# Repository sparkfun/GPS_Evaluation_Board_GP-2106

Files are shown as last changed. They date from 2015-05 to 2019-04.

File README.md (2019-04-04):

**NOTE:** *This product has been retired from our catalog. If you are looking for more up-to-date info, please check out some of these resources to see how other users are still hacking and improving on this product.*
* *[SparkFun Forum](https://forum.sparkfun.com/)*
* *[Comments Here on GitHub](https://github.com/sparkfun/GPS_Evaluation_Board_GP-2106/issues)*
* *[IRC Channel](https://www.sparkfun.com/news/263)*

SparkFun GPS Evaluation Board - GP-2106
========================================

SparkFun GPS Evaluation Board - GP-2106

[*SparkFun GPS Evaluation Board - GP-2106 (GPS-10995)*](https://www.sparkfun.com/products/10995)

The GP-2106 Evaluation Board features everything you need to get the [GP-2106 module](https://www.sparkfun.com/products/retired/10890) talking to your system. 
Because the GP-2106 is a 1.8V module, we’ve provided level-shifting for 3.3 and 5V systems. 
The board also features a PPS status LED, on/off button and an FTDI Basic compatible header!

Repository Contents
-------------------

* **/Hardware** - Eagle design files (.brd, .sch)
* **/Production** - Production panel files (.brd)

Documentation
--------------
* **[SparkFun Fritzing repo](https://github.com/sparkfun/Fritzing_Parts)** - Fritzing diagrams for SparkFun products.
* **[SparkFun 3D Model repo](https://github.com/sparkfun/3D_Models)** - 3D models of SparkFun products. 

License Information
-------------------
This product is _**open source**_! 

The **hardware** is released under [Creative Commons ShareAlike 4.0 International](https://creativecommons.org/licenses/by-sa/4.0/).

Please use, reuse, and modify these files as you see fit. Please maintain attribution to SparkFun Electronics and release anything derivative under the same license.

Distributed as-is; no warranty is given.

- Your friends at SparkFun.

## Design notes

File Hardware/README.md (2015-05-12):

SparkFun <PRODUCT NAME> Design Files
=====================================

The .sch and .brd files hare are Eagle CAD schematic and PCB design files from SparkFun Electronics.
A freeware version of Eagle can be found [here](http://www.cadsoftusa.com/download-eagle/freeware/). 

License
---------
This product is open source! 
The hardware is released under [Creative Commons ShareAlike 4.0 International](https://creativecommons.org/licenses/by-sa/4.0/).

Please use, reuse, and modify these files as you see fit. Please maintain attribution to SparkFun Electronics and release anything derivative under the same license.

Distributed as-is; no warranty is given.

- Your friends at SparkFun.

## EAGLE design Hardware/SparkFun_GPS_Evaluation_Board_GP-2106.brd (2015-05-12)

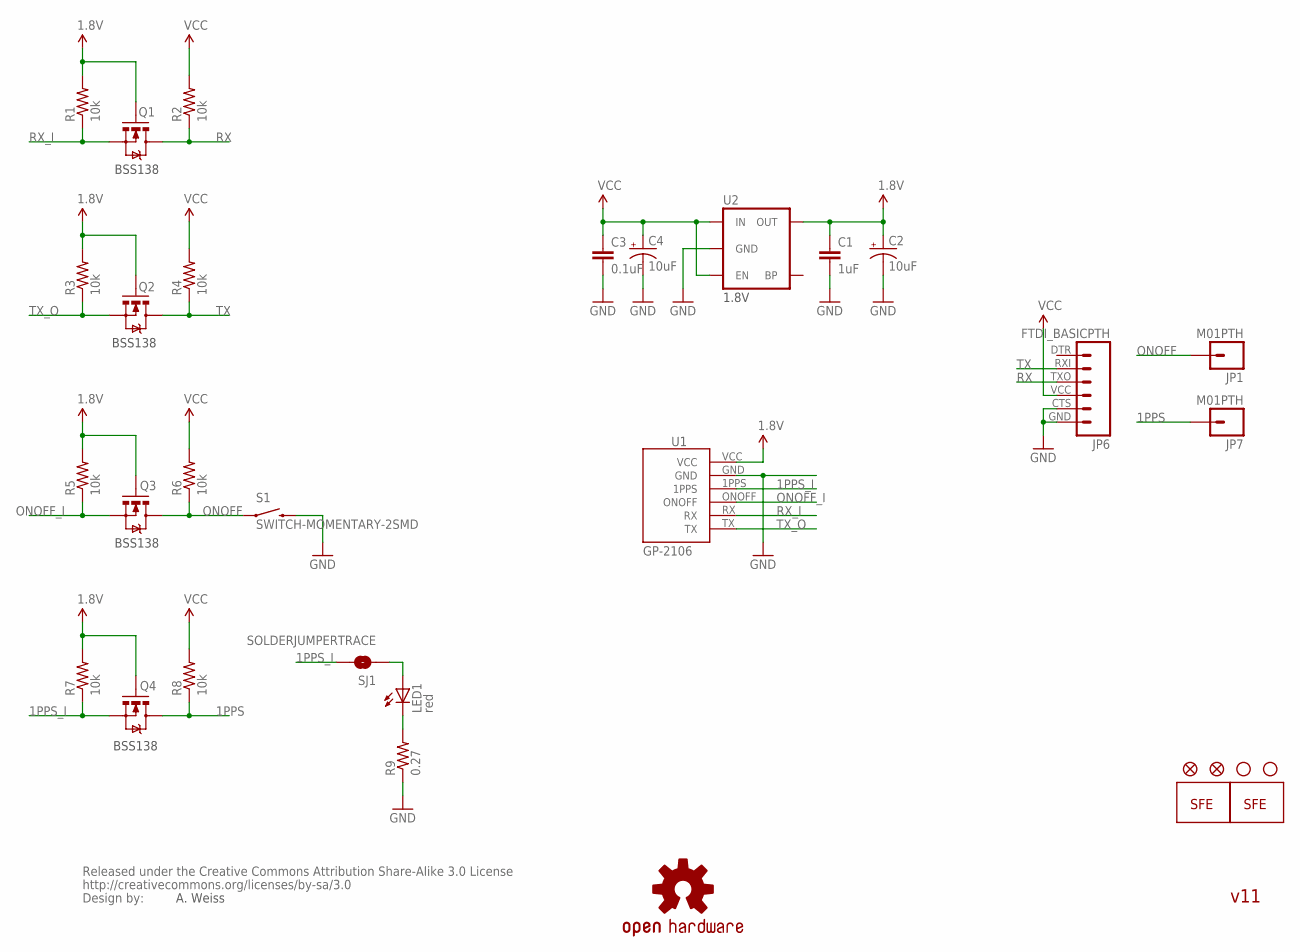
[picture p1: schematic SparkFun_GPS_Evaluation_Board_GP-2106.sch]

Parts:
C1: 1uF; 0402-CAP
C2, C4: 10uF; EIA3216
C3: 0.1uF; 0402-CAP
JP1, JP7: M01PTH; 1X01
JP2, JP3: STAND-OFF
JP4: LOGO-SFESK; SFE-LOGO-FLAME
JP5: LOGO-SFENEW; SFE-NEW-WEBLOGO
JP6: FTDI_BASICPTH; FTDI_BASIC
JP8, JP9: FIDUCIALUFIDUCIAL; MICRO-FIDUCIAL
LED1: red; LED-0603
Q1, Q2, Q3, Q4: MOSFET-NCHANNELSMD; SOT23-3
R1, R2, R3, R4, R5, R6, R7, R8: 10k; 0402-RES
R9: 0.27; 0402-RES
S1: SWITCH-MOMENTARY-2SMD; TACTILE_SWITCH_SMD
SJ1: SOLDERJUMPERTRACE; SJ_2S-TRACE
U1: GP-2106
U2: V_REG_LDOSMD2; SC70
U$7: OSHW-LOGOS; OSHW-LOGO-S
U$8: CREATIVE_COMMONS

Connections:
1.8V: C1.1, C2.A (+), Q1.1 (G), Q2.1 (G), Q3.1 (G), Q4.1 (G), R1.2, R3.2, R5.2, R7.2, U1.VCC, U2.5 (OUT)
1PPS: JP7.1, Q4.3 (D), R8.1
1PPS_I: Q4.2 (S), R7.1, SJ1.2, U1.1PPS
GND: C1.2, C2.C (-), C3.2, C4.C (-), JP6.CTS (5), JP6.GND (6), R9.1, S1.3 (2), U1.GND, U2.2 (GND)
unnamed: LED1.C, R9.2
unnamed: LED1.A, SJ1.1
ONOFF: JP1.1, Q3.3 (D), R6.1, S1.1
ONOFF_I: Q3.2 (S), R5.1, U1.ONOFF
RX: JP6.TXO (3), Q1.3 (D), R2.1
RX_I: Q1.2 (S), R1.1, U1.RX
TX: JP6.RXI (2), Q2.3 (D), R4.1
TX_O: Q2.2 (S), R3.1, U1.TX
VCC: C3.1, C4.A (+), JP6.VCC (4), R2.2, R4.2, R6.2, R8.2, U2.1 (IN), U2.3 (EN)

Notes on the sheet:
1.8V
BSS138
A. Weiss
v11

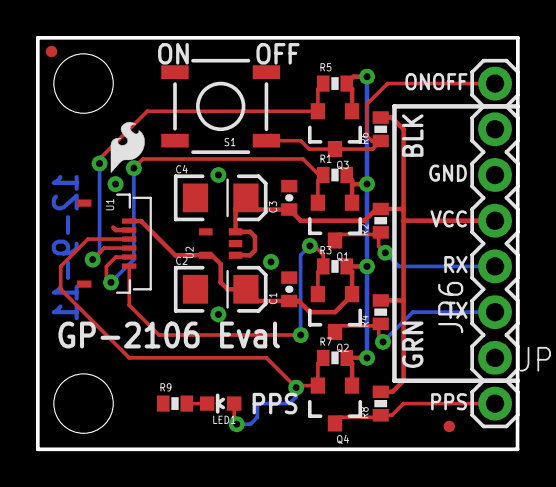
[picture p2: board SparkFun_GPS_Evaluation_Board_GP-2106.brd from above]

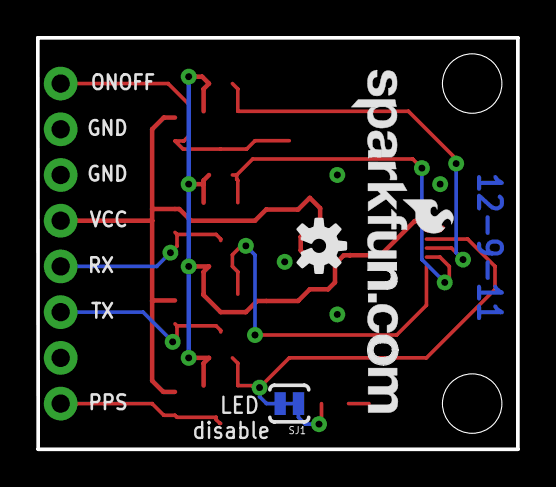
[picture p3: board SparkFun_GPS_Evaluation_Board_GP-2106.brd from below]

Board: 2 copper layers, 26.7 x 22.9 mm, 33 parts (3 on the bottom side), 13 nets.

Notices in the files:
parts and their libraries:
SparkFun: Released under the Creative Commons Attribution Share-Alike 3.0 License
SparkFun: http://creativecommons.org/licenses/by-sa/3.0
